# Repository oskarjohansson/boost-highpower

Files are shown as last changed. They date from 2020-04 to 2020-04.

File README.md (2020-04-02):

# Boost highpower
> Created by Oskar Johansson

**This is a synchronous boost module when the cheap 2A boost don't have the capacity to deliver enough powaer.**   

## Goals 
> Goals of this project
```
- Create a boost converter for at least 10A 
- Handle 5 - 40 V input 
- Handle 5 - 60 V output
```

## Directories 
```
Boost highpower
├── document        # Generic document folder
│   ├── datasheet   # Datasheet for hardware components  
├── hardware        
│   ├── pcb         # Schematic, layout and production files
│   │   └── gerber  # Production files
│   │   └── library # Library for project
└── img        # Thermal tests 
  ```

## Hardware 
> The hardware is pretty much the same used in Robot-SM project [RobotSM20-linefollower](https://github.com/caselabbet/robotsm20-linefollower) with following changes 
```
- Input capacitor to handle 5 - 35 V 
- Output capacitor to handle 5 - 55 V
- Potentiometer to control output
- Terminal blocks for wire
- Wide solderpads to solder wire 
```
The boost is consisting of a TPS43061, which is a *synchronous boost controller*, i.e. uses two external transistors instead of one transistor and a diode. This minimizes the losses in the diode that would have been about 5 - 7 W at 10A. 

When using the provided trimpot together with the resistors there is a hardware limit that unables to go beyond 55 V to output. Since the feedback reference is 1.22 V, you can find two resistors together with a trimpot to hold a certain intervall, as in the Matlab below.
```matlab
% Vfeedback is 1.22V 
syms Rsl Rsh
Rtrim = 10000;    
Vouth = 55;
Voutl = 5; 
eq1 = Voutl == 1.22*((Rsh)/(Rsl+Rtrim)+1);
eq2 = Vouth == 1.22*((Rsh+Rtrim)/(Rsl)+1);
solution = solve([eq1,eq2]);
Rsl = double(solution.Rsl);
Rsh = double(solution.Rsh);
Rshl_disp = sprintf('Resistor feedback with 10k trimpot, Rsl: %d Ohm, Rsh: %d Ohm \nGives a Vout of 5 to 55 V',Rsl,Rsh);
disp(Rshl_disp)
```
### Schematic 
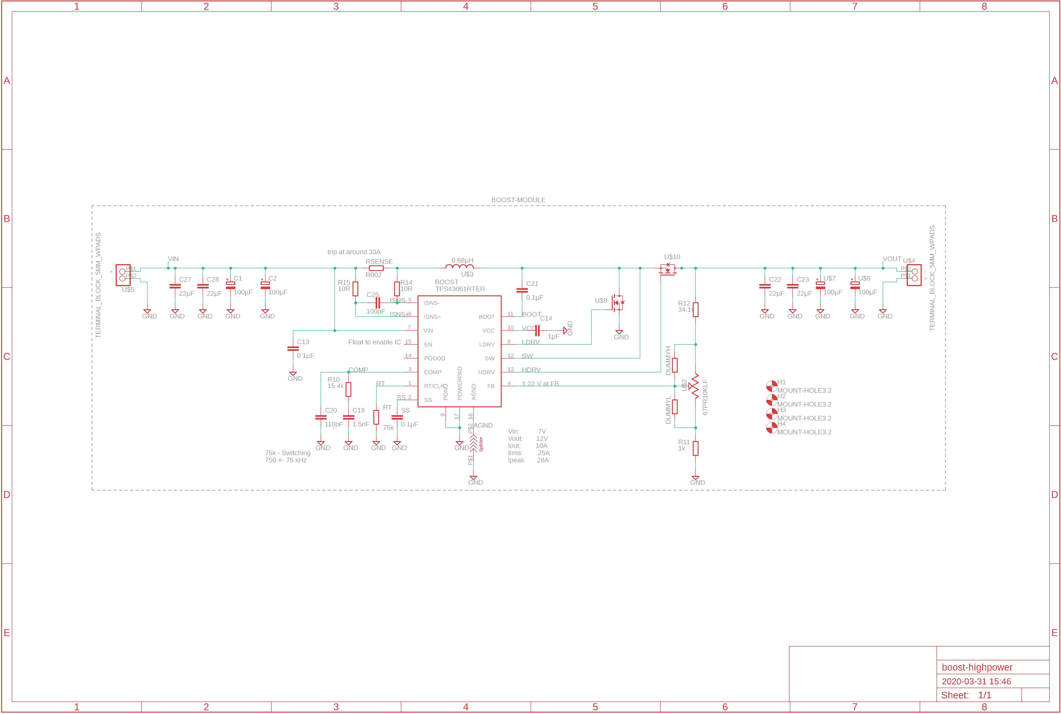
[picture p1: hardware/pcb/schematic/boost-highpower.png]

### Rendered images
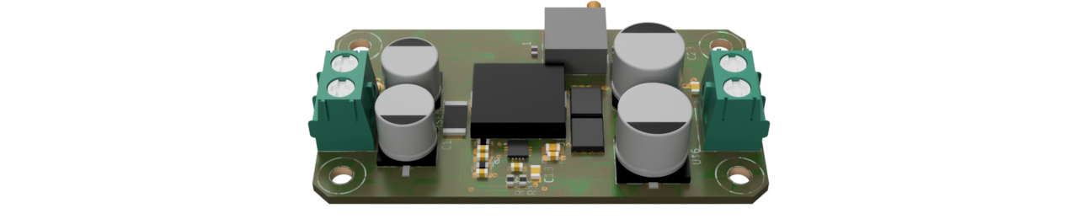
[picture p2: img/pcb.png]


### BOM 
| Device | Mfr nbr | Quantity  | Value |
| :--- | :--- | ---: | ---: |
| Boost controller | TPS43061 | 1 | - |
| Terminal block | 1935161 | 2 | - |
| Power inductor | SRP1238A-R82M | 1 | 0.82 µH |
| Potentiometer | 67PR10KLF | 1 | 10k |
| N-Mosfet | CSD19502Q5BT | 2 | 80V100A | 
| Current resistor | R2512W | 1 | R002 |
| Electrolytic cap | VZH-101M1KTR-1010 | 2 | 100 µF |
| Electrolytic cap | 865080653016 | 2 | 100 µF |
| Resistor | SMD 0603 | 5 | 2x 10R, 1k, 31.4k, 75k |
| Capacitor | SMD 0603 | 6 | 100 pF, 110 pF, 1.5 nF, 0.1 µF, 1µF |
| Capacitor | SMD 0805 | 6 | 2x 0.1 µF, 4x 22µF |

## Usage of the boost module 
```
- Connect inputside to 4.5 - 35 V. 
- Control with an multimeter the output.
- Connect the output.
```

## License
> This project is created with MIT license. 



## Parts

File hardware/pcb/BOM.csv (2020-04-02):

Qty | Value | Device | Package | Parts | Description | DESCRIPTION | HEIGHT | MANUFACTURER_NAME | MANUFACTURER_PART_NUMBER | MOUSER_PART_NUMBER | MOUSER_PRICE-STOCK | POPULARITY | SPICEPREFIX
2 |  | R-EU_R0201 | R0201 | DUMMYH, DUMMYL | RESISTOR, European symbol |  |  |  |  |  |  | 0 | R
1 | 0.1µF | C-EUC0603 | C0603 | SS | CAPACITOR, European symbol |  |  |  |  |  |  | 73 | C
2 | 0.1µF | C-EUC0805 | C0805 | C13, C21 | CAPACITOR, European symbol |  |  |  |  |  |  | 88 | C
1 | 0.68µH | SRP1238A-XXXX | INDM135125X330N | U$3 | Inductor
1 | 1.5nF | C-EUC0603 | C0603 | C19 | CAPACITOR, European symbol |  |  |  |  |  |  | 73 | C
1 | 100pF | C-EUC0603 | C0603 | C26 | CAPACITOR, European symbol |  |  |  |  |  |  | 73 | C
2 | 100µF | CAP_VZH | CAPAE1030X1000N | U$6, U$7
2 | 100µF | WCAP-ASLL-WE50V100µF | CAPAE830X850N | C1, C2
2 | 10R | R-EU_R0603 | R0603 | R14, R15 | RESISTOR, European symbol |  |  |  |  |  |  | 70 | R
1 | 110pF | C-EUC0603 | C0603 | C20 | CAPACITOR, European symbol |  |  |  |  |  |  | 73 | C
1 | 15.4k | R-EU_R0603 | R0603 | R10 | RESISTOR, European symbol |  |  |  |  |  |  | 70 | R
1 | 1k | R-EU_R0603 | R0603 | R11 | RESISTOR, European symbol |  |  |  |  |  |  | 70 | R
1 | 1µF | C-EUC0603 | C0603 | C14 | CAPACITOR, European symbol |  |  |  |  |  |  | 73 | C
4 | 22µF | C-EUC0805 | C0805 | C22, C23, C27, C28 | CAPACITOR, European symbol |  |  |  |  |  |  | 88 | C
1 | 34.1k | R-EU_R0603 | R0603 | R12 | RESISTOR, European symbol |  |  |  |  |  |  | 70 | R
1 | 67PR10KLF | 67PR10KLF | 67PR10KLF | U$2
1 | 75k | R-EU_R0603 | R0603 | RT | RESISTOR, European symbol |  |  |  |  |  |  | 70 | R
2 | CSD17301Q5A | CSD17301Q5A | Q5A | U$9, U$10 | CSD17301Q5A
4 | MOUNT-HOLE3.2 | MOUNT-HOLE3.2 | 3,2 | H1, H2, H3, H4 | MOUNTING HOLE with drill center marker |  |  |  |  |  |  | 7
1 | R002 | R-EU_R2512W | R2512W | RSENSE | RESISTOR, European symbol |  |  |  |  |  |  | 0 | R
1 | SPLITTER | SPLITTER | SPLITTER | U$1
2 | TERMINAL_BLOCK_5MM_WPADS | TERMINAL_BLOCK_5MM_WPADS | TERMINAL_5MM_WITH_SOLDERPADS | U$4, U$5
1 | TPS43061RTER | TPS43061RTER | QFN50P300X300X80-17N | BOOST | Low Iq, Synchronous Boost Controller with Wide Input Voltage and 5.5V Gate Drive for Low Qg NexFETs | Low Iq, Synchronous Boost Controller with Wide Input Voltage and 5.5V Gate Drive for Low Qg NexFETs | 0.8mm | Texas Instruments | TPS43061RTER | 595-TPS43061RTER | https://www.mouser.com/Search/Refine.aspx?Keyword=595-TPS43061RTER

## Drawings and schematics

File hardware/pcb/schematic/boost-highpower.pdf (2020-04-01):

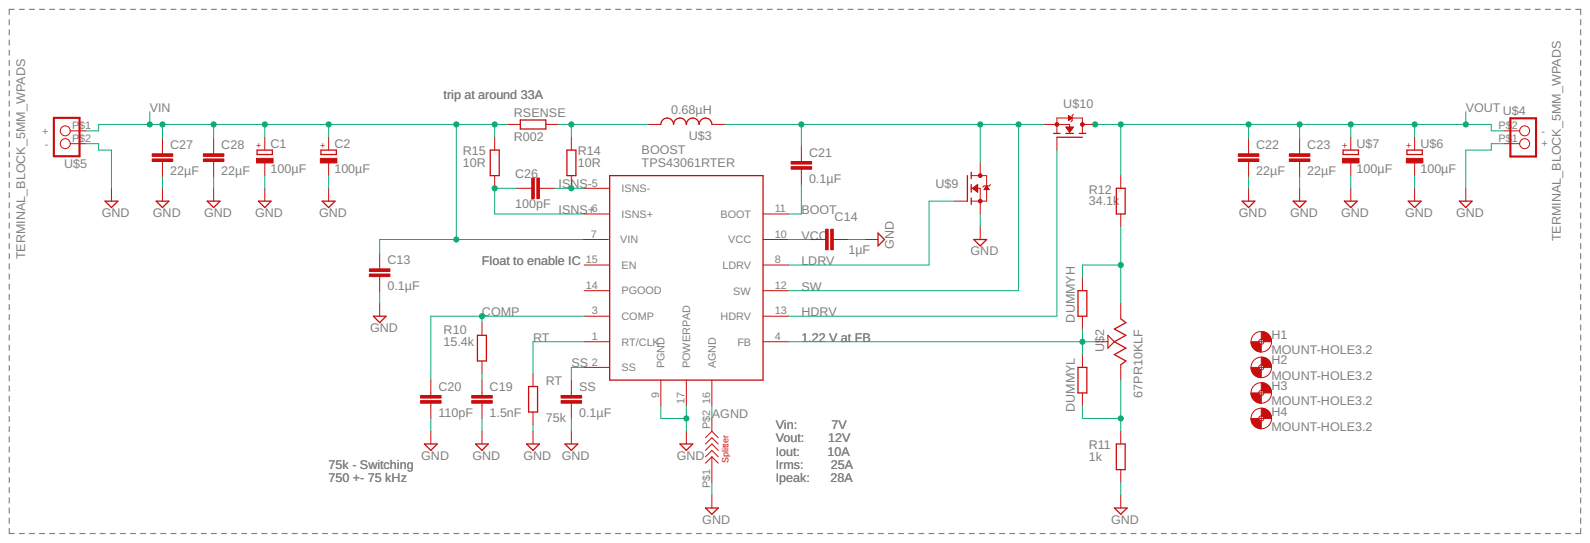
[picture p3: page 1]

Float to enable IC

MOUNT-HOLE3.2 MOUNT-HOLE3.2

2020-04-01 17:16 f=0.75 C:\Users\oskar\Dropbox\Dokument\Projekt\boost-highpower\hardware\pcb\boost-highpower\boost-highpower.sch (Sheet: 1/1)

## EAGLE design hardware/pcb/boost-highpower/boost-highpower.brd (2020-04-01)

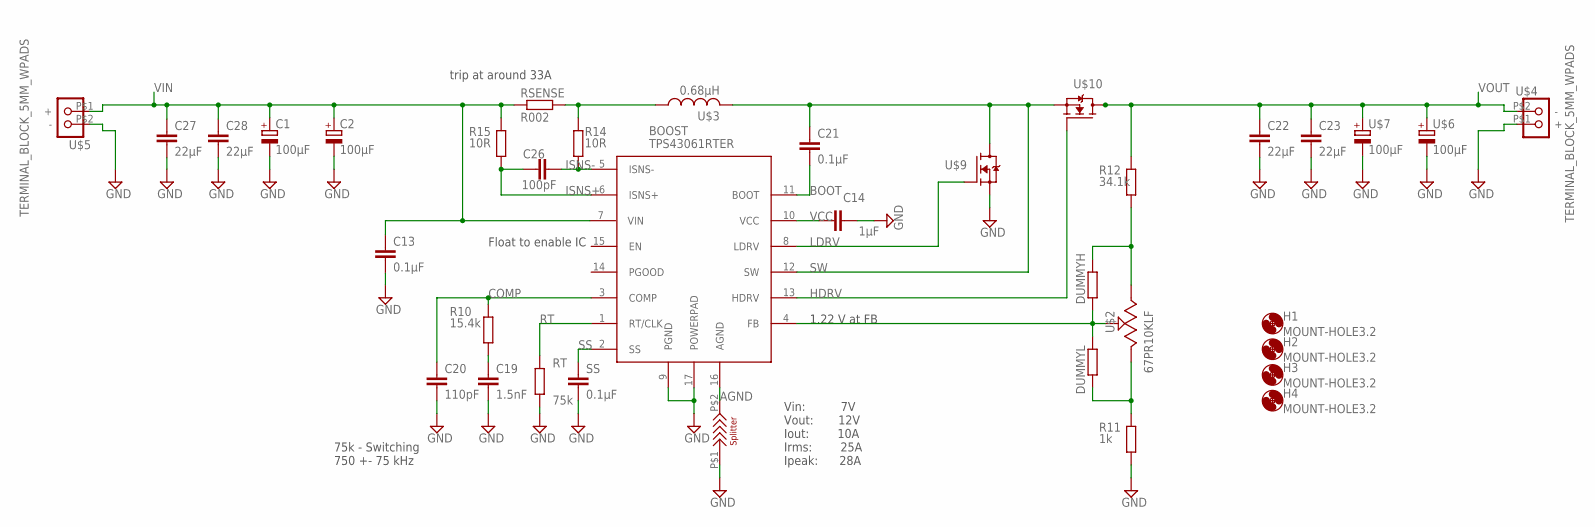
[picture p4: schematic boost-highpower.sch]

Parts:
BOOST: TPS43061RTER; QFN50P300X300X80-17N
C1, C2: 100µF; CAPAE830X850N
C13, C21: 0.1µF; C0805
C14: 1µF; C0603
C19: 1.5nF; C0603
C20: 110pF; C0603
C22, C23, C27, C28: 22µF; C0805
C26: 100pF; C0603
DUMMYH: R-EU_R0201; R0201
DUMMYL: R-EU_R0201; R0201
H1, H2, H3, H4: MOUNT-HOLE3.2; 3,2
R10: 15.4k; R0603
R11: 1k; R0603
R12: 34.1k; R0603
R14, R15: 10R; R0603
RSENSE: R002; R2512W
RT: 75k; R0603
SS: 0.1µF; C0603
U$1: SPLITTER
U$2: 67PR10KLF
U$3: 0.68µH; INDM135125X330N
U$4, U$5: TERMINAL_BLOCK_5MM_WPADS; TERMINAL_5MM_WITH_SOLDERPADS
U$6, U$7: 100µF; CAPAE1030X1000N
U$9, U$10: CSD17301Q5A; Q5A

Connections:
AGND: BOOST.16 (AGND), U$1.P$2 (2)
BOOT: BOOST.11 (BOOT), C21.2
COMP: BOOST.3 (COMP), C20.1, R10.2
GND: BOOST.9 (PGND), BOOST.17 (POWERPAD), C1.2 (-), C2.2 (-), C13.2, C14.2, C19.2, C20.2, C22.2, C23.2, C27.2, C28.2, R11.1, RT.1, SS.2, U$1.P$1 (1), U$4.P$1 (+), U$5.P$2 (-), U$6.2 (-), U$7.2 (-), U$9.1 (S), U$9.2 (S), U$9.3 (S)
HDRV: BOOST.13 (HDRV), U$10.4 (G)
ISNS+: BOOST.6 (ISNS+), C26.1, R15.1
ISNS-: BOOST.5 (ISNS-), C26.2, R14.1
LDRV: BOOST.8 (LDRV), U$9.4 (G)
unnamed: DUMMYH.2, R12.1, U$2.P$3 (3)
unnamed: DUMMYL.1, R11.2, U$2.P$1 (1)
unnamed: C19.1, R10.1
unnamed: R14.2, RSENSE.2, U$3.1
unnamed: BOOST.4 (FB), DUMMYH.1, DUMMYL.2, U$2.P$2 (2)
RT: BOOST.1 (RT/CLK), RT.2
SS: BOOST.2 (SS), SS.1
SW: BOOST.12 (SW), C21.1, U$3.2, U$9.5 (D), U$9.6 (D), U$9.7 (D), U$9.8 (D), U$9.9 (D), U$10.1 (S), U$10.2 (S), U$10.3 (S)
VCC: BOOST.10 (VCC), C14.1
VIN: BOOST.7 (VIN), C1.1 (+), C2.1 (+), C13.1, C27.1, C28.1, R15.2, RSENSE.1, U$5.P$1 (+)
VOUT: C22.1, C23.1, R12.2, U$4.P$2 (-), U$6.1 (+), U$7.1 (+), U$10.5 (D), U$10.6 (D), U$10.7 (D), U$10.8 (D), U$10.9 (D)

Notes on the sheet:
75k - Switching 750 +- 75 kHz
1.22 V at FB
trip at around 33A
Vin: 7V Vout: 12V Iout: 10A Irms: 25A Ipeak: 28A
Float to enable IC

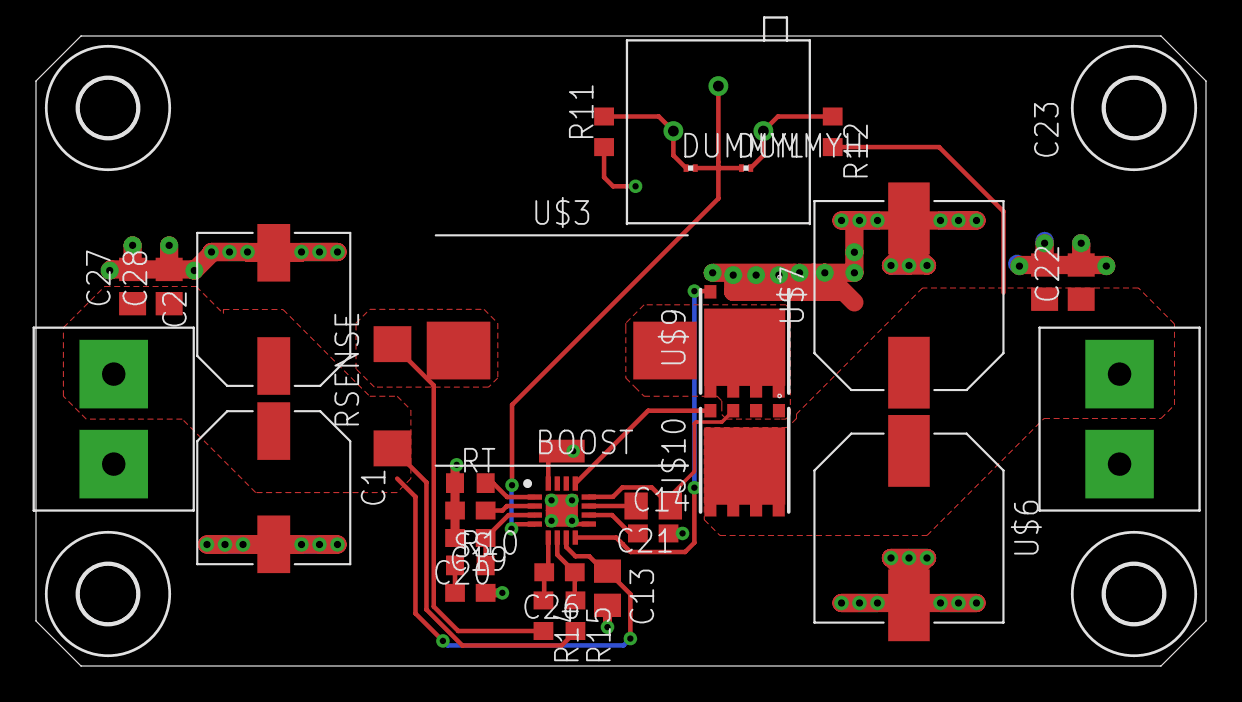
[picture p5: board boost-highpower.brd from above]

Board: 2 copper layers, 65.0 x 35.0 mm, 36 parts (0 on the bottom side), 19 nets.

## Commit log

2020-03-25 Create project and copy boost from robotsm20-linefollower
    [boost-highpower.brd, boost-highpower.sch]
2020-03-25 moved some components
    [boost-highpower.brd]
2020-03-26 Moved components to a first place
    [boost-highpower.brd, boost-highpower.sch]
2020-03-26 Routed board
    [boost-highpower.brd, boost-highpower.sch]
2020-03-29 Added 10A to silkscreen
    [boost-highpower.brd]
2020-03-31 Changed cap to 50V and 100V to meet requirement
    [boost-highpower.brd, boost-highpower.sch]
2020-04-01 Export schematic
2020-04-01 Render PCB
2020-04-01 Corrected typo in name of used controller
    [boost-highpower.brd]
2020-04-01 Update README.md
    Added images, schematic, more information about the module
2020-04-02 Added BOM
